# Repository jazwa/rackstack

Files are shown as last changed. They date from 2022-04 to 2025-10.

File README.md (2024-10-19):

# rackstack

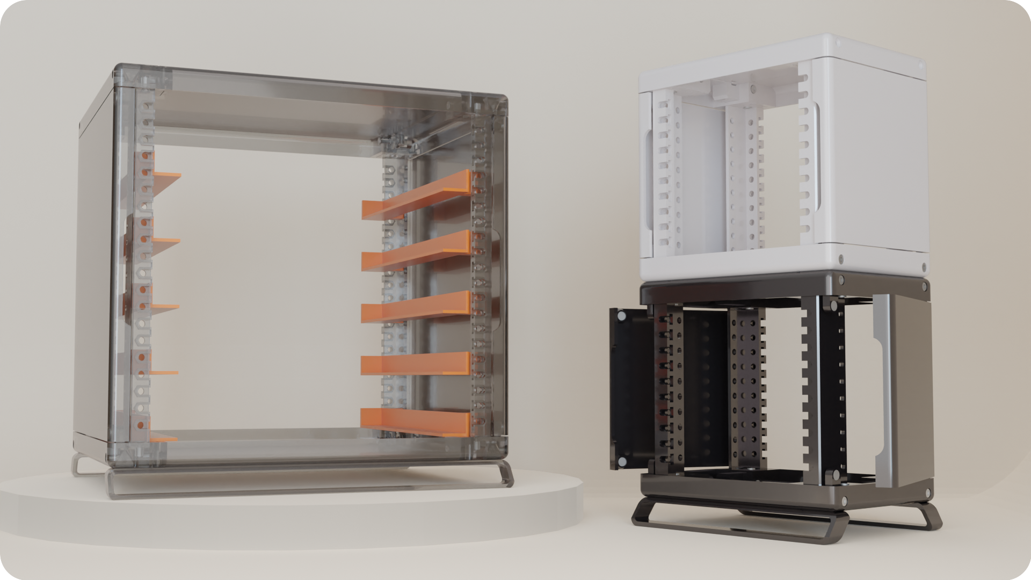
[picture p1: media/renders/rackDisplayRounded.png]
display


### A modular 3d-printable mini rack system
- ***Mount Anything:*** Perfect for organizing SBCs, mini PCs, small switches, power hubs, etc.
- ***Fully customizable:*** Fully written in OpenSCAD. Everything, from the dimensions of the rack, to the roundness of the corners, can be modified with a simple code change.
- ***Printable from home:*** Designed to be printed with conventional FDM printers. Requires minimal supports when printing, and final assembly needs only a few easy-to-source parts. 
- ***No cage nuts:*** Sliding hex nut design for the front rails allows one to easily mount items, without dealing with cage nuts.
- ***Stackable:*** Individual racks can be easily stacked and fastened together. Mix and match different color and design combinations!

## Assembly

Pre-generated STLs for roughly 200mm^3 (mini), 180mm^3 (micro), and 100mm^3 (nano) rack frames can be found in the [stl](stl) dir.
These STLs are generated from the files in [rack/print](rack/print) - further information about printing these parts 
(supports, orientation) can be found in these files.

### Assembly Instructions
Please see [the assembly guide](./assembly-guide).

### BOM - Required Tools:
- 3d FDM Printer - build size requirements depend on configured rack profile
- M3 Allen Key (for constructing the rack)
- M4 Allen Key (for mounting rack-mount items)

### BOM - Single Rack:

| Item | Name | Quantity | Comment |
|---|---|---|---|
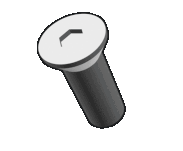
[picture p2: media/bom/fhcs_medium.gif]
|  | M3x12 FHCS | 12 | Extras are useful and inexpensive. If you plan on eventually stacking multiple racks together, don't hesitate to get a lot more. |
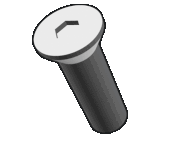
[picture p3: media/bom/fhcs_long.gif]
|  | M3x16 FHCS | 16 | ☝️ |
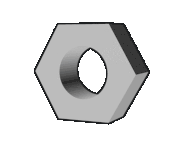
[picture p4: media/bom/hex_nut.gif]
|  | M3 hex nut | 28 | ☝️ |
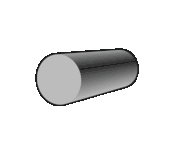
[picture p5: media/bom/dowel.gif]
|  | 3x10 steel dowel pin | 4 | 3mm diameter, 10mm height |
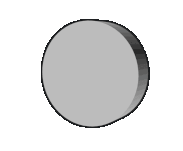
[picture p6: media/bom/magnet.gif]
|  | 6x2 neodymium disc magnet | 8 | 6mm diameter, 2mm height |
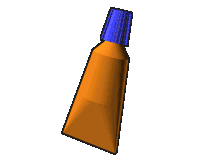
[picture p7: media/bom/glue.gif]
|  | super glue | \>= 2ml  | Used to glue magnets to plastic |

### Printing - Single Rack:
| Part | Quantity |
|---|---|
| [Left Y-Bar](./rack/print/yBarLeft_P.scad) | 2 |
| [Right Y-Bar](./rack/print/yBarRight_P.scad) | 2 |
| [X-Bar](./rack/print/xBar_P.scad) | 4 |
| [Main Rail](./rack/print/mainRail_P.scad) | 4 |
| [Left Side Wall](./rack/print/sideWallLeft_P.scad) | 1 |
| [Right Side Wall](./rack/print/sideWallRight_P.scad) | 1 |
| [XY-Plate](./rack/print/xyPlate_P.scad) | 2 |
| [Feet](./rack/print/rackFeet_P.scad) (optional) | 2 |

#### Notes: 
- ⚠️ Before printing the actual parts. It's recommended to print this evaluation part: [eval_P.scad](./rack/print/eval_P.scad) to test tolerances. 
  If you find the fits too tight/loose, you can adjust them [here](./config/print.scad). Please make sure also adjust the layer height in that file, too.
- Omitted actual plastic for printing. Any conventional 3d printing plastic should do (PLA, PETG, ABS),
but beware of PLA's thermal limits. Higher infill is recommended for all parts.
- For joining two racks, you will need to print 4 [rackJoiners](./rack/print/rackJoiner_P.scad), as well as 8 M3 hex nuts, and 8 M3x12 FHCS.
- Main front rails use M4 hex nuts and screws.
- Side rails are mounted using M3 hex nuts and screws.

## Configuring + Generating STLs
A python script:  [rbuild.py](./rbuild.py) is provided to generate different project stls. **Before running the script**, please 
configure the path to the OpenSCAD binary in [rbuild.py](./rbuild.py).

Requirements:
  - `openscad` CLI binary
  - `python3`

### Examples:
Generate all project files for the `micro` profile:

`python3 rbuild.py -b all -c micro`

This will build all the parts defined in [rack/print](./rack/print), and put the STLs in [stl/micro](./stl/micro). 
You can also provide a `-dz {n}` parameter to adjust the height of the generated rack. Configuring other rack
variables can be done in [config/rackframe.scad](./config/rackFrame.scad).

For generating a specific part, and putting it into a new `stl/custom` target directory: 

`python3 rbuild.py -b yBar -c micro -t custom`

`rbuild.py` also support an optional `--nightly` flag, which will run a nightly build of OpenSCAD. Please make sure the
path to the nightly build is also configured in [rbuild.py](./rbuild.py).

### ⚠️ Important:
Before committing to a full print, please try printing an evaluation print: [eval_P.scad](./rack/print/eval_P.scad) to test tolerances.
It is very likely you will need to edit the default tolerances in [print.scad](./config/print.scad) for a nice fit.

## Trays, Boxes, etc

Some parametric rack mount systems can be found in [rack-mount](./rack-mount). The following rack-mount systems 
are currently supported:
- [Enclosed Box](./rack-mount/enclosed-box): For mounting box-shaped objects, without the need for any mounting holes on the box.
- [Tray](./rack-mount/tray): Simple tray mounted using only the front rails. Can be configured to have screw mounts at the bottom of the tray.
- [Patch Panel](./rack-mount/patch-panel): Linear patch panel array. Number of keystone slots can be configured.
- [Angle Brackets](./rack-mount/angle-bracket): Simple Angle Bracket mounting system. Derived from the Enclosed Box system.

## Rack Mount Catalog

There is a small catalog of various pre-configured rack-mountable parts in the [catalog](./rack-mount/catalog) directory. Please feel free to add anything even remotely
useful!

## Designing rack-mount items

Some useful variables for designing your own rack-mount items can be found in [rack-mount/dimensionHelper.scad](./rack-mount/dimensionHelper.scad).

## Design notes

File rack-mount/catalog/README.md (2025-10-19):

# Rack Mount Catalog

A hodgepodge of various pre-configured rack mount parts. 

Please feel free to submit a pull request for any new parts you end up creating! Code quality is no object here.

Command to rebuild the preview images:
```
find . -name "*.scad" -exec ./build_catalog_preview.sh {} \;
```

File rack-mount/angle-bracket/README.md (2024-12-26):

# Angle Bracket System

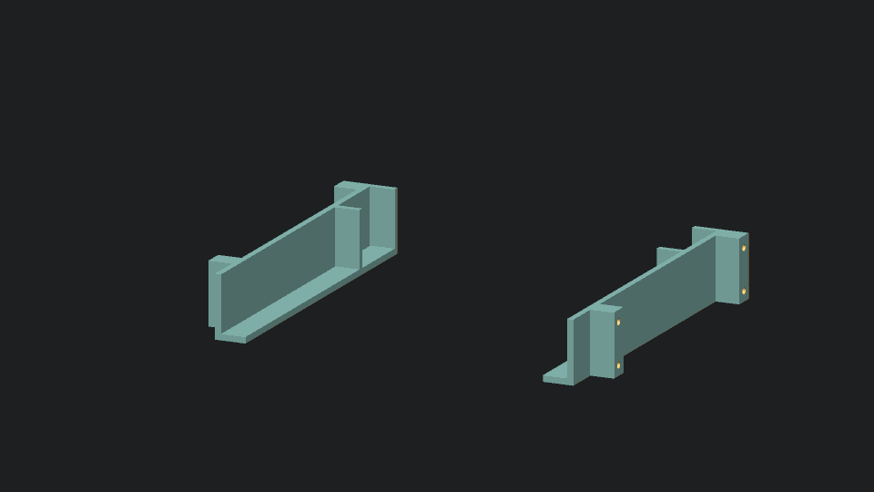
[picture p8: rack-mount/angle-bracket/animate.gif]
demo


Please see [entry.scad](./entry.scad) for config and building. Make sure the correct rack profile is configured in [rackFrame.scad](../../config/rackFrame.scad).

### BOM:

| Item | Name | Quantity | Comment |
|---|---|---|---|
|  | M3x12 FHCS | 8 | Extras are useful and inexpensive. If you plan on eventually stacking multiple racks together, don't hesitate to get a lot more. |
|  | M3 hex nut | 8 | ☝️ |

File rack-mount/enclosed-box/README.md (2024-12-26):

# Enclosed Box Mounting System

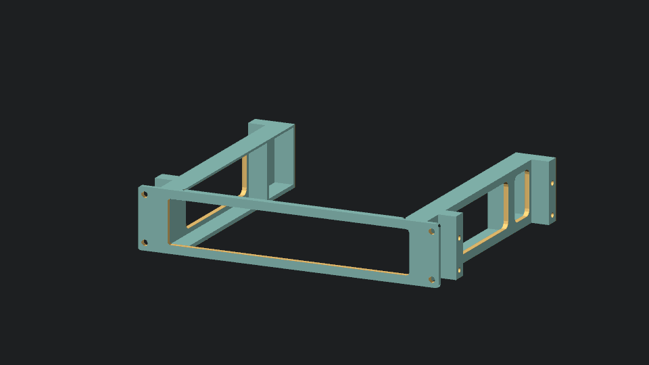
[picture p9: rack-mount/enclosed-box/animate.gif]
demo


Please see [entry.scad](./entry.scad) for config and building. Make sure the correct rack profile is configured in [rackFrame.scad](../../config/rackFrame.scad).

- This system comprises three parts: two side rails, and a front plate.
- This system is useful for mounting heavier box-shaped things. It works by first sliding in the box inside the side rails (which secures `x`, `z`, and one half of the `y` axis), and then mounting the front plate along the main rails (fully securing the `y` axis).
- Side rails will most likely require supports to print.
- For wider boxes (nearing the `maxUnitWidth` of the rack), you will have to set `recessSideRail` to true. This is so the side rails do not collide with the main rack rails. 

### BOM:

| Item | Name | Quantity | Comment |
|---|---|---|---|
|  | M3x12 FHCS | 8 | Extras are useful and inexpensive. If you plan on eventually stacking multiple racks together, don't hesitate to get a lot more. |
|  | M3 hex nut | 8 | ☝️ |
|  | M4x12 FHCS | 4 | ☝️ |
|  | M4 hex nut | 4 | ☝️ |

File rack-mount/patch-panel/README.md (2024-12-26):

# Patch Panel

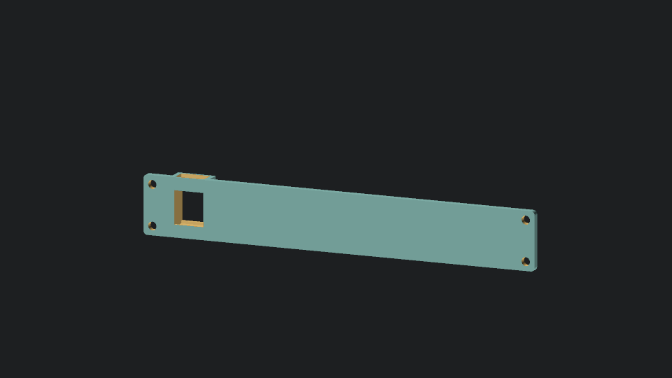
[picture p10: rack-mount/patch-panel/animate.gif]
demo


Please see [entry.scad](./entry.scad) for config and building. Make sure the correct rack profile is configured in [rackFrame.scad](../../config/rackFrame.scad).

- Mount RJ-45 keystone jacks with this part.
- Single part. Can be printed without supports.

### BOM:

| Item | Name | Quantity | Comment |
|---|---|---|---|
|  | M4x12 FHCS | 4 | Extras are useful and inexpensive. If you plan on eventually stacking multiple racks together, don't hesitate to get a lot more. |
|  | M4 hex nut | 4 | ☝️ |

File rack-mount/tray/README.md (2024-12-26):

# Tray Mounting System

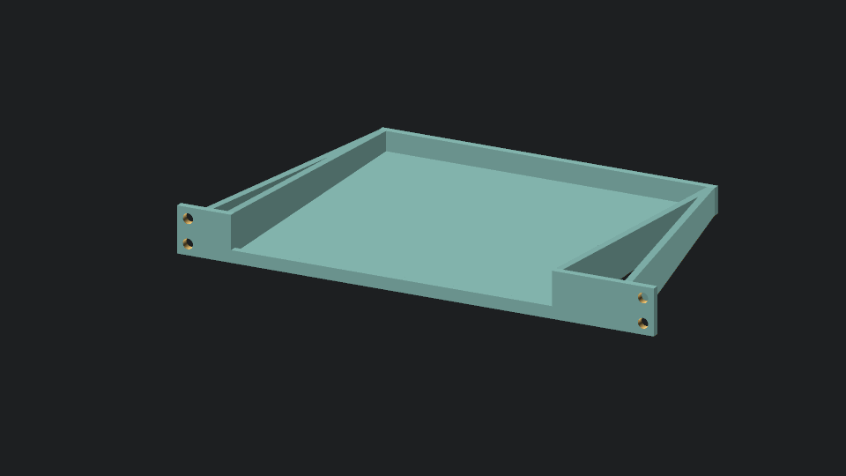
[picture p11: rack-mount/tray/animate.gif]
demo


Please see [entry.scad](./entry.scad) for config and building. Make sure the correct rack profile is configured in [rackFrame.scad](../../config/rackFrame.scad).

- Mount on front rails. 
- Single part. Can be printed without supports.
- Includes support for custom bottom screws (see `mountPoints` in config). This is useful for SBCs and mini PCs with bottom screws.

### BOM:

| Item | Name | Quantity | Comment |
|---|---|---|---|
|  | M4x12 FHCS | 4 | Extras are useful and inexpensive. If you plan on eventually stacking multiple racks together, don't hesitate to get a lot more. |
|  | M4 hex nut | 4 | ☝️ |

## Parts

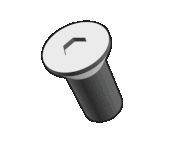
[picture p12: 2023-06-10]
media/bom/fhcs_short.gif

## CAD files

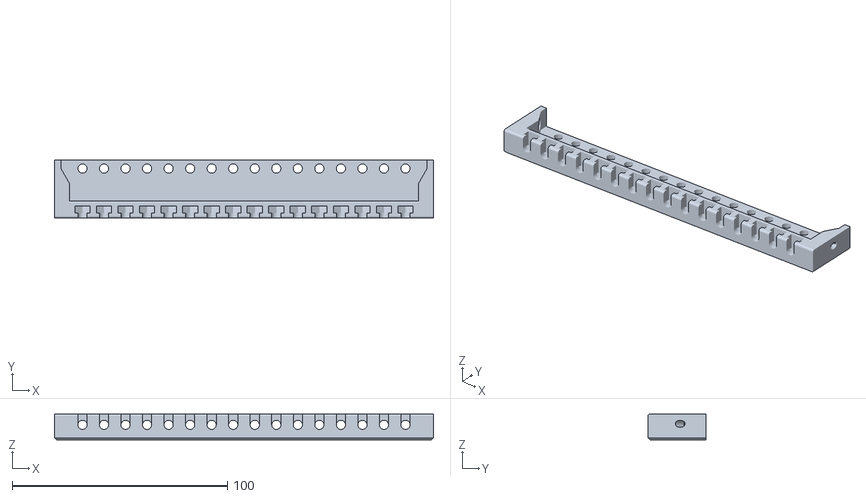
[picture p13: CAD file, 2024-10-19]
stl/mini/rack/mainRail_P.stl
176.0 x 27.0 x 12.0

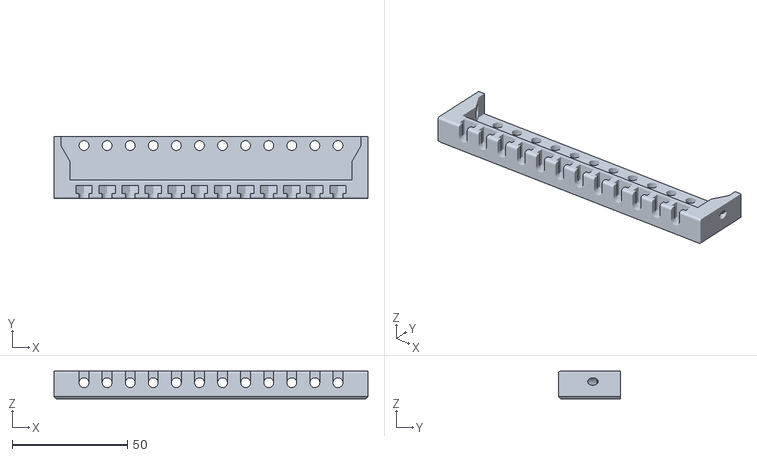
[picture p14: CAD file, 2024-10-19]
stl/micro/rack/mainRail_P.stl
136.0 x 27.0 x 12.0

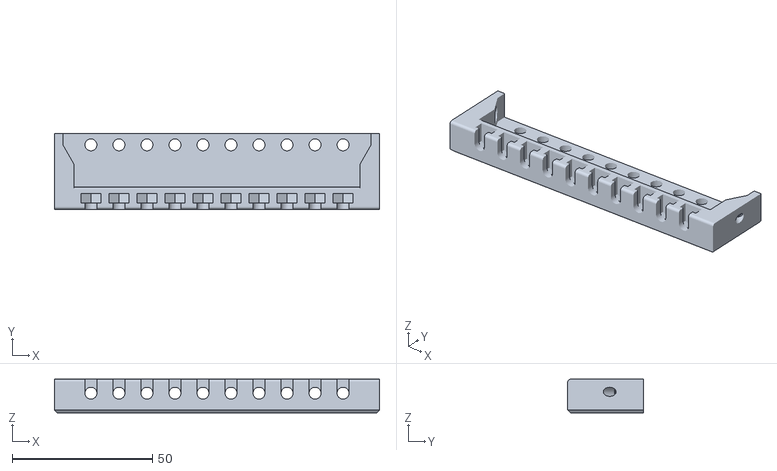
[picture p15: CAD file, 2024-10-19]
stl/nano/rack/mainRail_P.stl
116.0 x 27.0 x 12.0

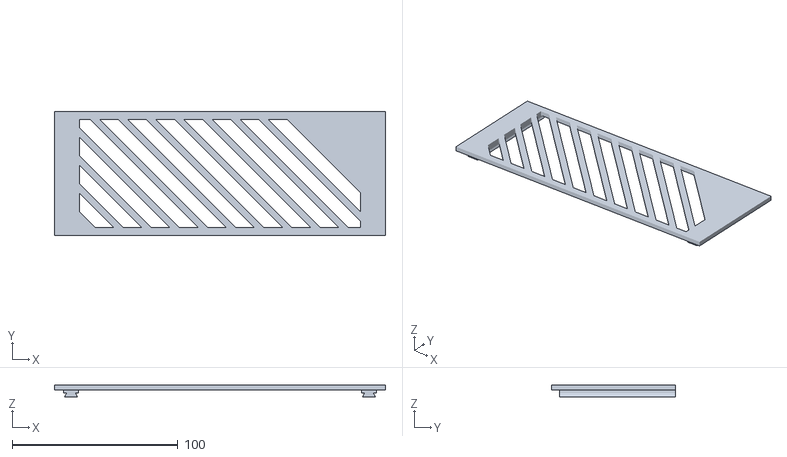
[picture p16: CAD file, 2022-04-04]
power/src/plate.stl
200.0 x 75.0 x 7.33

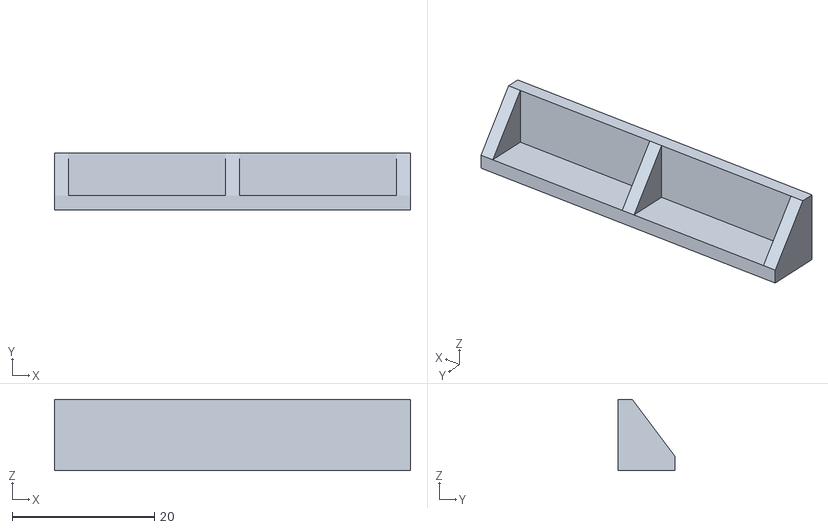
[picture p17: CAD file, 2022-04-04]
power/stl/support1.stl
50.0 x 8.00 x 10.0

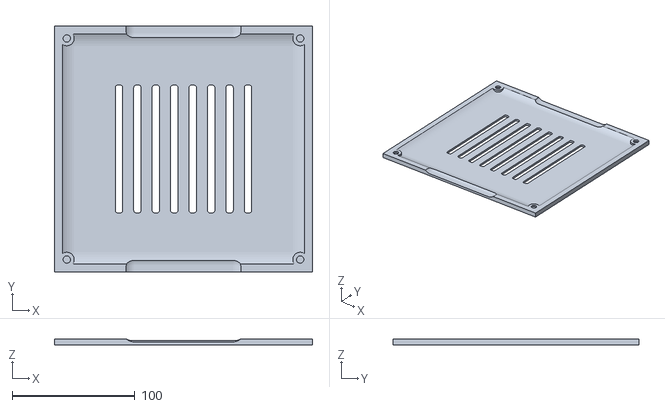
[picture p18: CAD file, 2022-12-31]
rack/body/side/side.stl
210.0 x 200.0 x 5.00

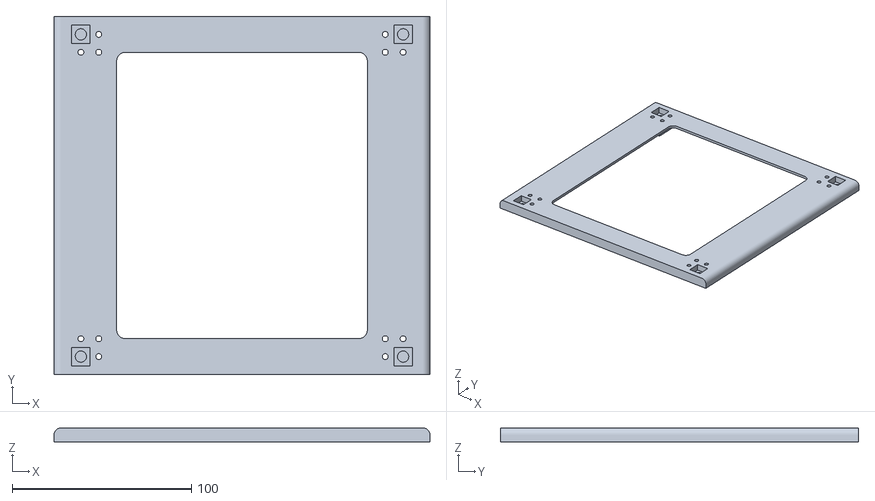
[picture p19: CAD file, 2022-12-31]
rack/body/top1.stl
210.0 x 200.0 x 8.01

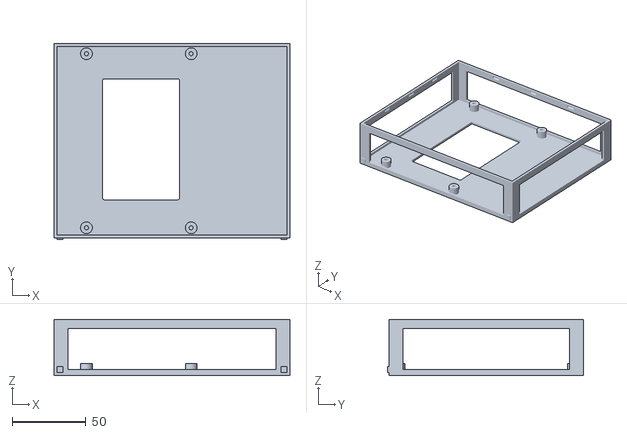
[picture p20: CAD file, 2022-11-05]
rack/rackCase.stl
160.0 x 133.0 x 38.0

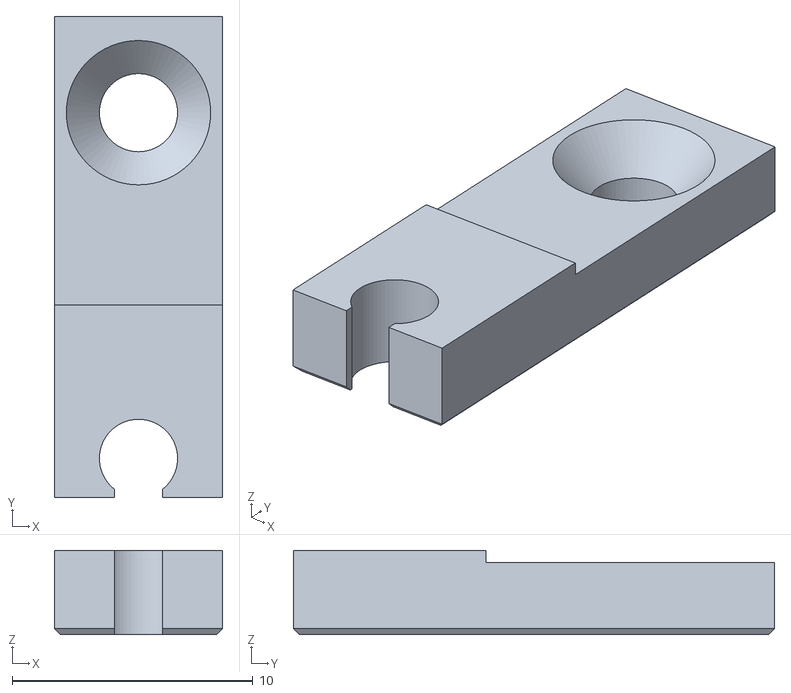
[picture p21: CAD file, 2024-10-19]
stl/micro/rack/hingeModule.stl
7.00 x 20.0 x 3.50

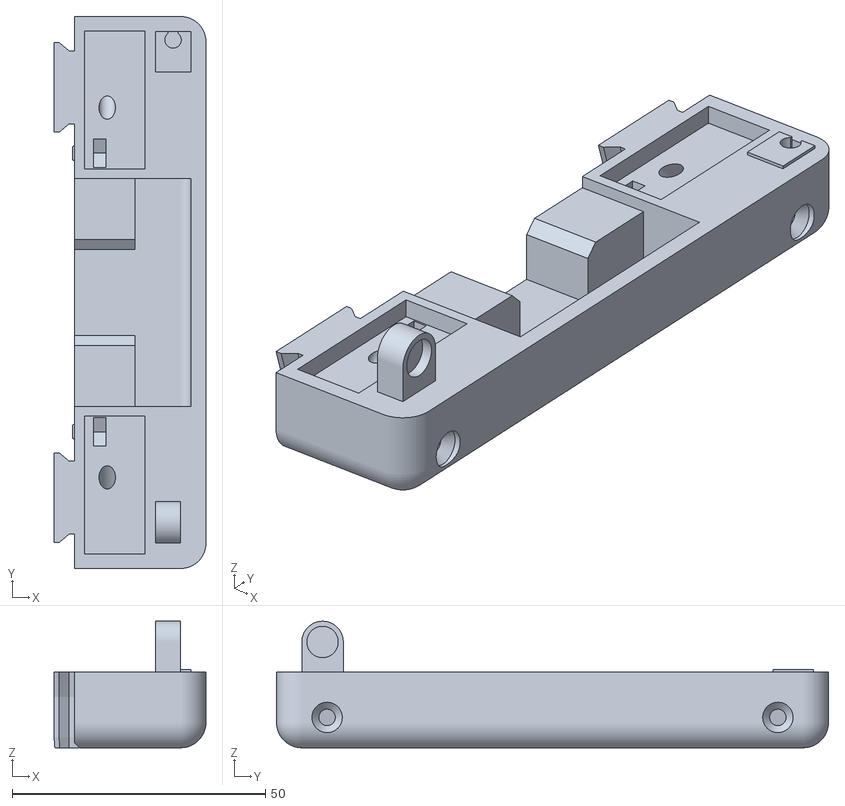
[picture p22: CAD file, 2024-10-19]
stl/nano/rack/yBarRight_P.stl
30.0 x 109.0 x 25.0

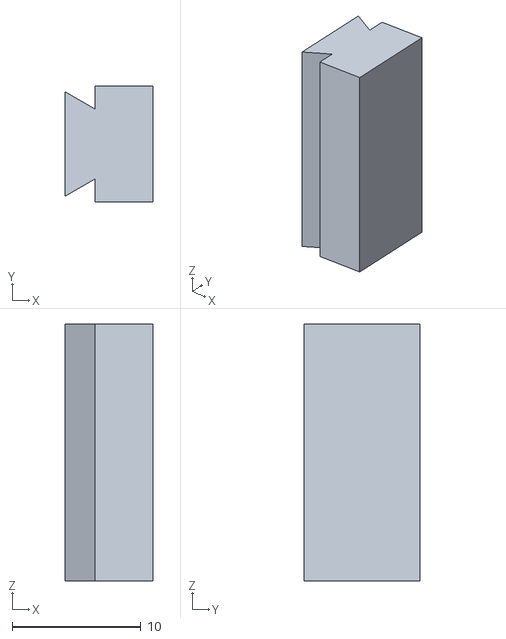
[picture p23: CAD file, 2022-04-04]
power/stl/railInsert.stl
6.85 x 9.00 x 20.0

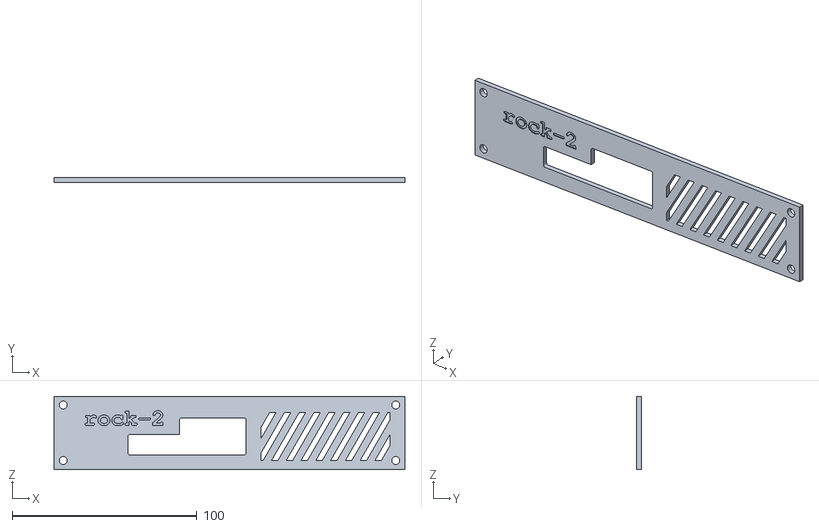
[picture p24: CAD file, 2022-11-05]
rack/rackCaseFrontPlate.stl
190.0 x 2.50 x 39.8

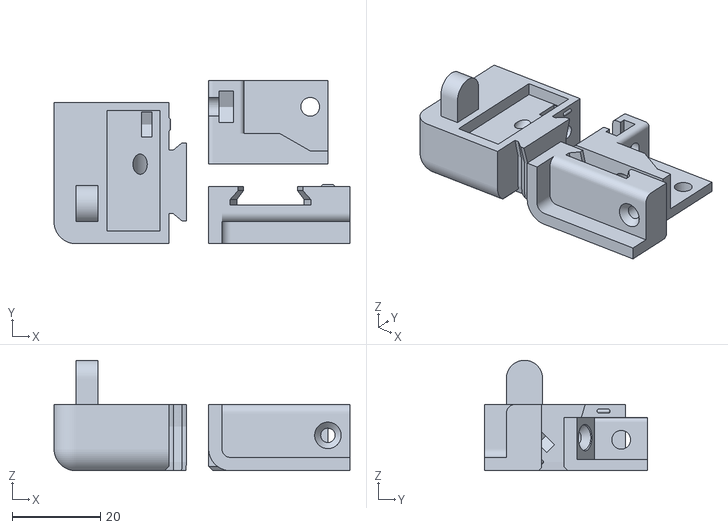
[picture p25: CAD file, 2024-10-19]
stl/micro/rack/eval_P.stl
67.0 x 37.0 x 25.0

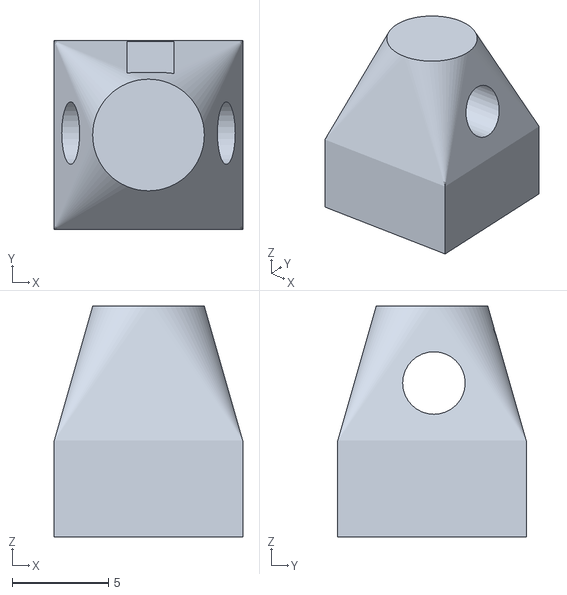
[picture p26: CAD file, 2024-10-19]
stl/mini/rack/stackConnectorBottom_P.stl
9.80 x 9.80 x 12.0

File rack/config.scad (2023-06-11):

/*
   case-files v2
   This file contains parameters used for declaring/generating a customized rack frame.

   - All dimensions are in millimetres (mm) unless stated otherwise.
   - "_N" appended to a module is meant to denote that this module is a negative volume, and should only be used to
     substract from other volumes. "_P" is meant to denote a positive value. Modules are positive by default.
*/
include <./profiles.scad>

// Manually set this variable to toggle profiles
profileName = "micro";

profile = getProfile(profileName);

defaultLayerHeight = 0.3;

function getConfig(name) = getConfigValue(profile, name);

// Maximum width for rack-mount units. Change this according your max expected enclosure width.
// Changing this will directly affect the required build volume.
maxUnitWidth = getConfig("maxUnitWidth");

// Maximum (recommended) unit depth. There technically isn't a max unit depth because there's no physical bound on
// how far a rack unit can extrude back. This parameter basically controls the distance between the front of the front
// rails and the back of the back rails. Changing this will directly affect the required build volume.
maxUnitDepth = getConfig("maxUnitDepth");

// Vertical distance between the midpoint of adjacent screws mounts. Affects build volume.
screwDiff = getConfig("screwDiff");

// Number screw slots on the main rail. Affects build volume.
numRailScrews = getConfig("numRailScrews");

// Screw type used for rackmount units. See screws.scad.
mainRailScrewType = getConfig("mainRailScrewType");

// Screw type used to affix side rails.
mainRailSideMountScrewType = getConfig("mainRailSideMountScrewType");

// Screw type used for constructing the actual rack frame.
rackFrameScrewType = getConfig("rackFrameScrewType");
// Currently, only m3 screws are supported here (tolerance issues)
assert(rackFrameScrewType == "m3");

// Fillet radius for main rack profile
baseRoundness = getConfig("baseRoundness");

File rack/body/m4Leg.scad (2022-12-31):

include <../../common.scad>
include <../screws.scad>


//slack = 0.5;
//m3Diameter = 3.0;
//m3Radius = m3Diameter/2.0;
//m3ptr = m3Radius + slack;

legWidth = 16;
legLength = 16;
legHeight = 60;

legFrontThickness = 6;
legSupportThickness = 4;

legWingThickness = 4;
legWingLength = 9;

// 9.5 to account for space for inserting hex nuts at the top
legWingWidth = 9.5+legSupportThickness;


module legWing() {
  difference() {
    cube(size=[legWingLength, legWingThickness, legWingWidth]);

    union() {
      translate(v=[4,0,10])
        rotate(a=[90,0,0])
        cylinder(r=m3RadiusSlacked, h=20, center=true);

      translate(v=[14,0,10])
        rotate(a=[90,0,0])
        cylinder(r=m3RadiusSlacked, h=20, center=true);
    }
  }
}

module base() {
    difference() {
      cube(size=[25,25,legWingThickness]);

      union() {
      translate(v=[20,20,0])
        cylinder(r=m3RadiusSlacked, h=100, center=true);

      translate(v=[10,10,0])
        cylinder(r=m3RadiusSlacked, h=100, center=true);

      translate(v=[20,10,0])
        cylinder(r=m3RadiusSlacked, h=100, center=true);

      translate(v=[10,20,0])
        cylinder(r=m3RadiusSlacked, h=100, center=true);
      }
      
    }
}

module baseLeg(legHeight) {
  union() {
    difference() {
      cube(size=[16,16, legHeight]);

      union() {
        translate(v=[4,6,0])
          cube(size=[16, 16, legHeight]);

        // compensate for differences between leg/wing thickness
        translate(v=[legSupportThickness,legSupportThickness,0])
          cube(size=[legWidth,legWidth,legSupportThickness+10]);

        translate(v=[legSupportThickness,legSupportThickness,legHeight-legWingWidth])
          cube(size=[legWidth,legWidth,legSupportThickness+10]);

      }
    }

    translate(v=[16,0,0])
      legWing();


    translate(v=[16,0,legHeight])
      mirror(v=[0,0,1]) {
      legWing();
    }

    mirror(v=[1,-1,0]) {
      translate(v=[16,0,0])
        legWing();


      translate(v=[16,0,legHeight])
        mirror(v=[0,0,1]) {
        legWing();
      }
    }

  }

  base();

  translate(v=[0,0,legHeight-legWingThickness])
    base();
}

*baseLeg(180);

module leg(ui) {
  assert(ui > 0);

  legLength = 20 + (ui-1)*10;
  
  difference() {
    baseLeg(legLength);

    union() {
        
      intersection() {
        union() {
          for (i = [1:ui-2]) {
            translate(v=[0,10,(i+1)*10])
              rotate(a=[0,90,0])
              *cylinder(h = 100, r = m3ptr, $fn=32, center=true);

            translate(v=[10,3,(i+1)*10])
              rotate(a=[90,-10,0])
              m4HexNutPocketNegative();
          }
        }      
        translate(v=[-1,-1,legWingWidth])
          cube(size=[1000,1000,legLength-2*legWingWidth]);
      }

      translate(v=[0,10,10])
        rotate(a=[0,90,0])
        cylinder(h = 100, r = m3ptr, $fn=32, center=true);

      translate(v=[0,10,ui*10])
        rotate(a=[0,90,0])
        cylinder(h = 100, r = m3ptr, $fn=32, center=true);


      translate(v=[10,0,10])
        rotate(a=[90,0,0])
        cylinder(h = 100, r = m3ptr, $fn=32, center=true);

      translate(v=[10,0,ui*10])
        rotate(a=[90,0,0])
        cylinder(h = 100, r = m3ptr, $fn=32, center=true);
    }
  }
}


//mirror(v=[1,0,0])
leg(20);

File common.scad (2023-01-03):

/* Some initial configurations and commonly used variables
   plus functions
*/

$fn=64;

eps=0.0001;

inf10 = 10;
inf50 = 50;
inf1000 = 1000;
inf = inf1000;

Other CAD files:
stl/nano/rack/hingeModule.stl
power/stl/topBarInsert.stl
rack/rackCaselid.stl
stl/micro/rack/rackFeet_P.stl
sinusoid.scad
cases/rack-tray/rack-tray.scad
cases/rack/base1.scad
cases/rpi/frontPlate.scad
cases/rpi/rpi2b.scad
cases/rpi/top.scad
config/common.scad
config/dowel.scad
config/magnet.scad
config/print.scad
config/rackFrame.scad
config/slack.scad
helper/apply.scad
helper/common.scad
helper/dovetail.scad
helper/filet.scad
helper/keystone.scad
helper/keystone1.scad
helper/keystone2.scad
helper/math.scad
helper/matrix.scad
helper/screws.scad
helper/sine.scad
helper/sinusoid.scad
helper/slack.scad
misc/bomAnimations.scad
power/src/Untitled.scad
power/src/base.scad
power/src/join.scad
power/stl/backPlate.stl
power/stl/feet.stl
power/stl/joinTest.stl
power/stl/joinTest\.stl
power/stl/legTest.stl
power/stl/plate.stl
power/stl/screwtest.stl
power/stl/support2.stl
power/stl/top.stl
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

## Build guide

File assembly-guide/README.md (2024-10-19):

# Rack Assembly Instructions

**Note**: Please see
- [BOM](../README.md#bom---single-rack) for required materials, beyond the actual 3D printed parts.
- [Print BOM](../README.md#printing---single-rack) for all the required 3D printed parts for a single rack.

## Instructions:
Slide in M3 hex nuts into the Y-bars - 4 times. Each corner should have 3 hex nuts:
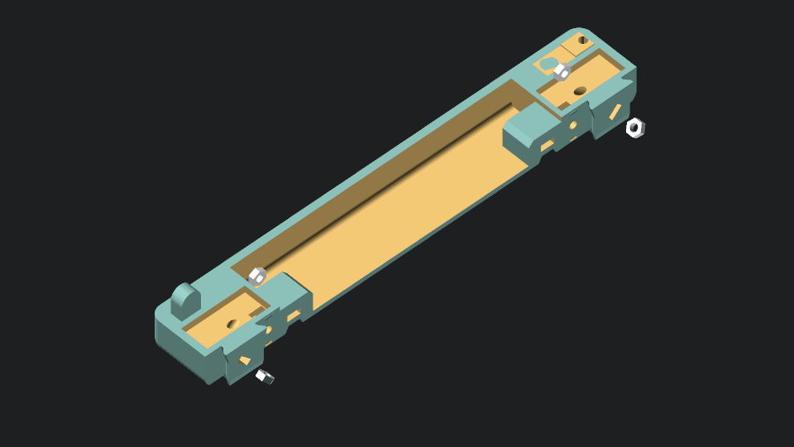
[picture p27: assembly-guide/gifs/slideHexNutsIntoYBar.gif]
slideHexNutsIntoYBar


Glue magnets into magnet side-modules on the Y-bars - 4 times:
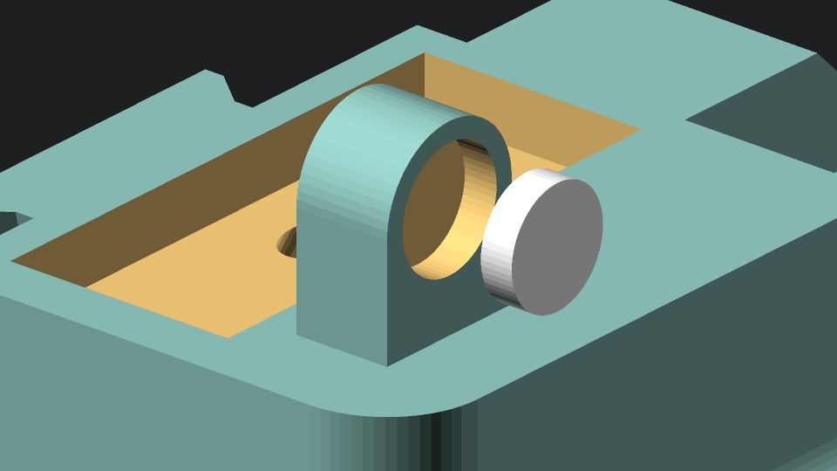
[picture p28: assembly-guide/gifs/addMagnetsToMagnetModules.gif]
addMagnetsToMagnetModules


Glue top and bottom magnets into side walls - 2 times:
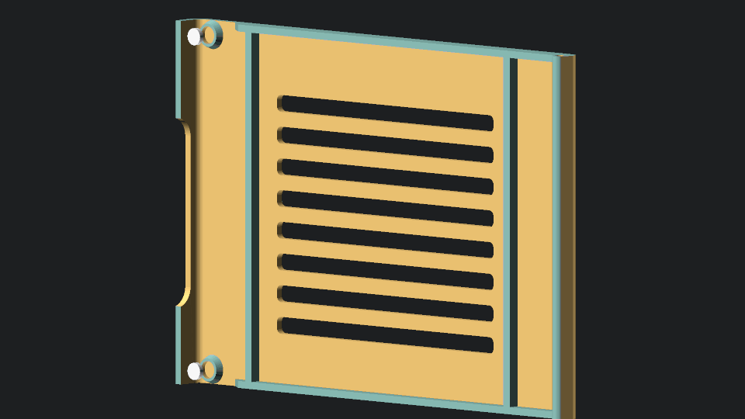
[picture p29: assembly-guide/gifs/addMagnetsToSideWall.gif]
addMagnetsToSideWall


Insert top and bottom dowel rods into side walls - 2 times:
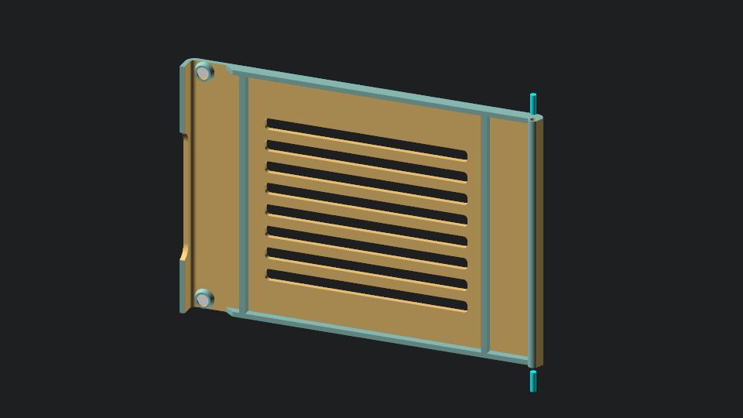
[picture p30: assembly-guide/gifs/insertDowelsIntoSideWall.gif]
insertDowelsIntoSideWall


Slide Y-bars into X-bars. Do this 2 times. You should end up with 2 trays. Orientation on the Y-bars matters here; make sure that the magnets are on the same side:
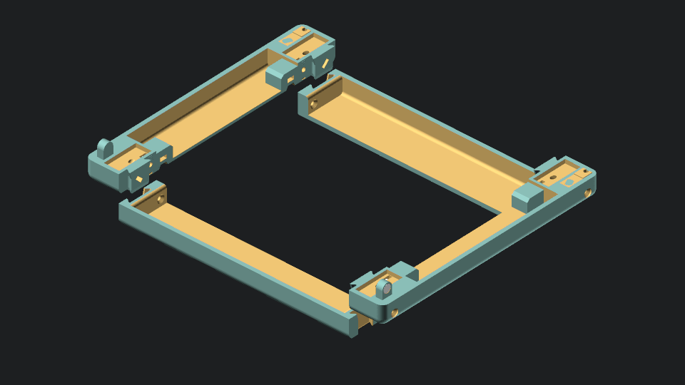
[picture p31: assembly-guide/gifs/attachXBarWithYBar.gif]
attachXBarWithYBar


Screw together Y-bars and X-bars using 4 M3x16 FHCS screws (one screw per corner) - 2 times: 
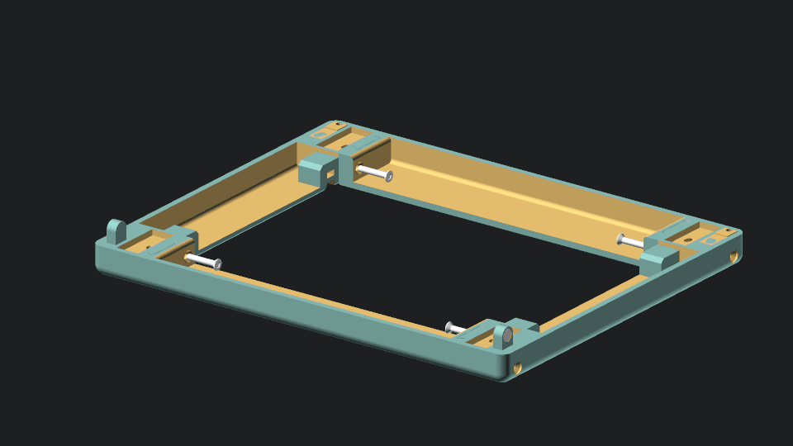
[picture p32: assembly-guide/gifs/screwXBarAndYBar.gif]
screwXBarAndYBar


<!-- This step is only needed if the fixedSideModules is set to false. -->
<!-- Screw in the side-modules with M3x8 FHCS screws. Orientation matters here. The magnets modules should be on the eventual front side, facing outwards, and the two hinge modules should be in the back. Do this 2 times (for both trays): -->
<!-- ![attachSideConnectorModulesToYBars](./gifs/attachSideConnectorModulesToYBars.gif) -->

Screw in the main rails with M3x16 FHCS screws.
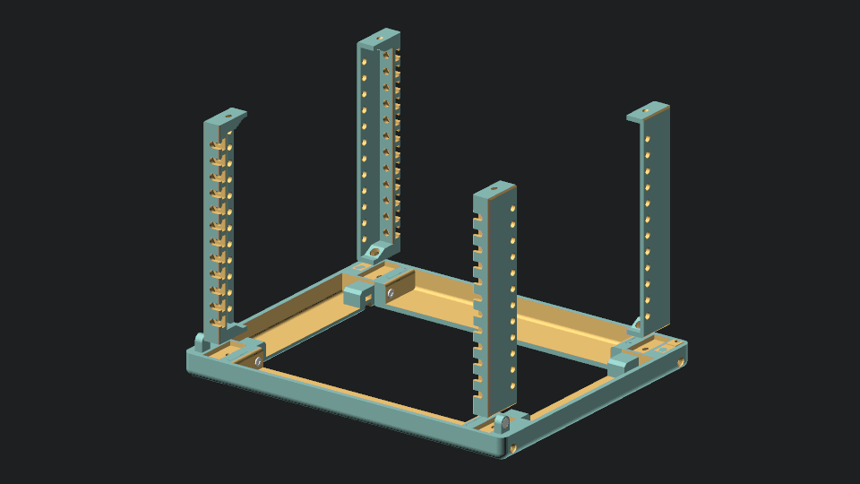
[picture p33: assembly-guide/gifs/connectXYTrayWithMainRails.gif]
connectXYTrayWithMainRails


Prop us the side wall using the side modules. Make sure the dowels are inserted properly, and the magnets align:
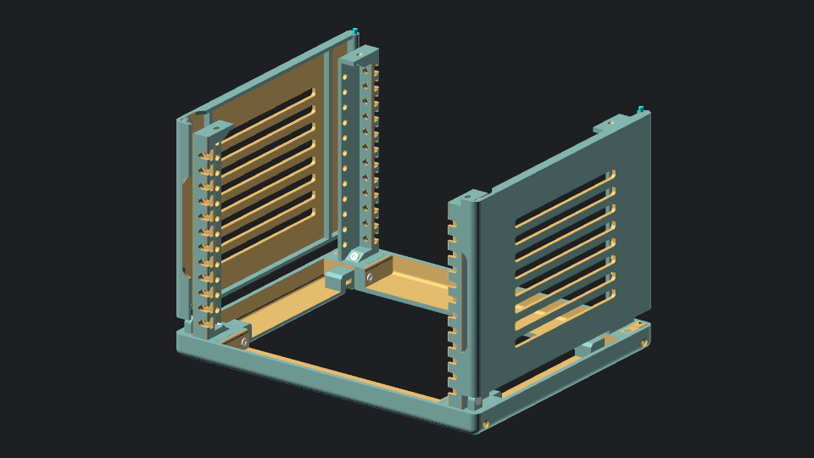
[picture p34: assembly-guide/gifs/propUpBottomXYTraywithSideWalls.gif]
propUpBottomXYTraywithSideWalls


Slide in the other (top) tray. Make sure the magnets and dowels align. Screw in the main rails with M3x16 FHCS screws:
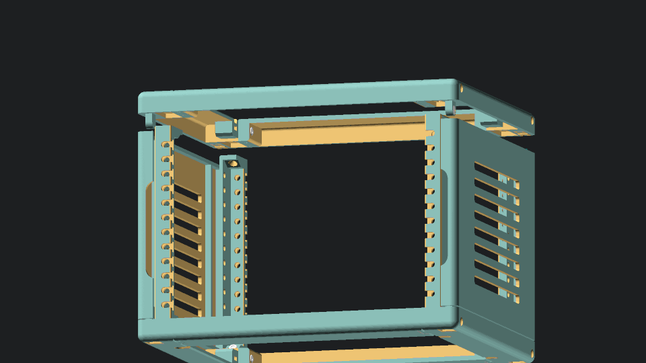
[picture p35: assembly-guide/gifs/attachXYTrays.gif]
attachXYTrays


Attach the top and bottom plates with 4 M3x12 screws each:
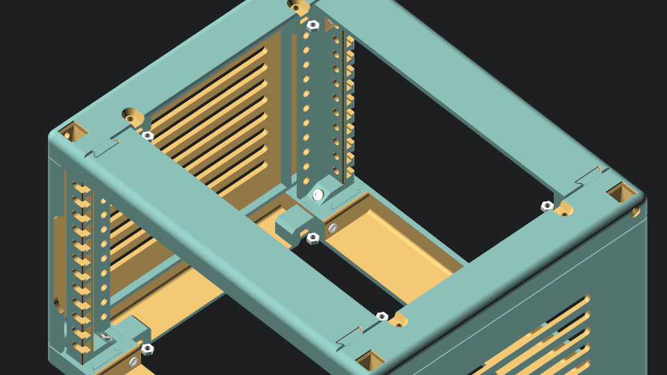
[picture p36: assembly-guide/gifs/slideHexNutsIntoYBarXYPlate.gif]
slideHexNutsIntoYBarXYPlate

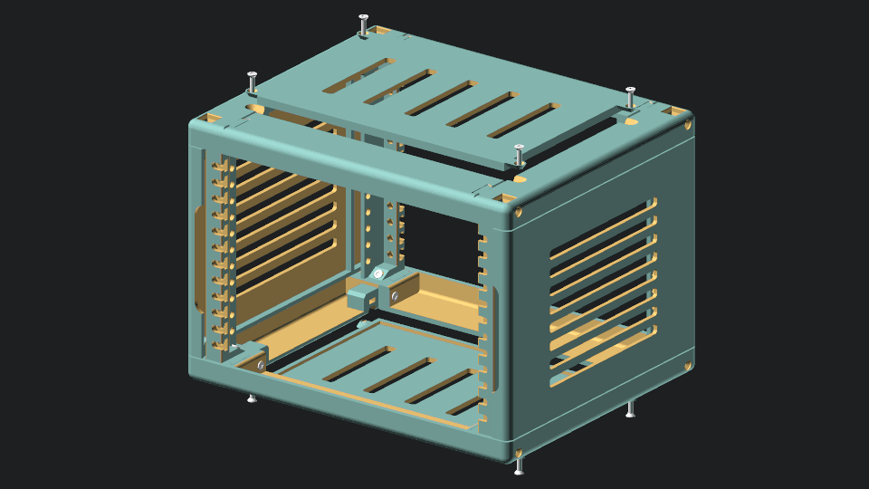
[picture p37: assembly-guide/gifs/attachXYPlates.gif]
attachXYPlates


Slide in hex nuts into feet - 2 times:
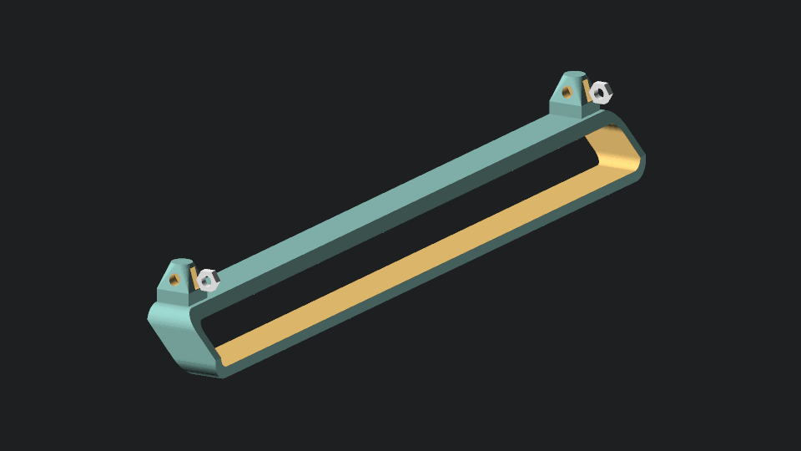
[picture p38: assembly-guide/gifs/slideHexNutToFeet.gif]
slideHexNutToFeet


Insert feet into the bottom of the rack: 
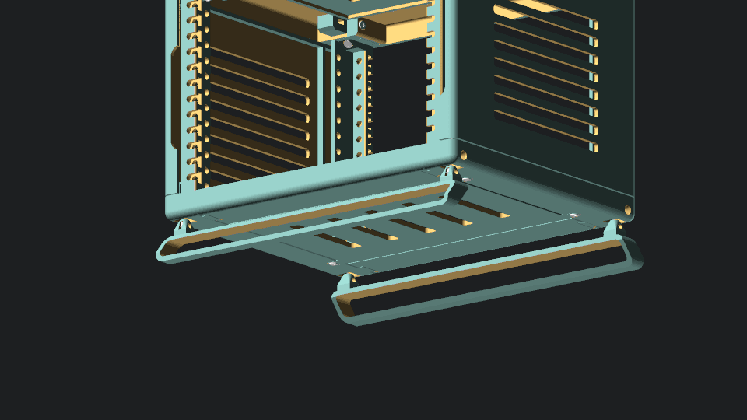
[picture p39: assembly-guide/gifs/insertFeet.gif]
insertFeet


Screw in feet using 4 M3x12 FHCS screws:
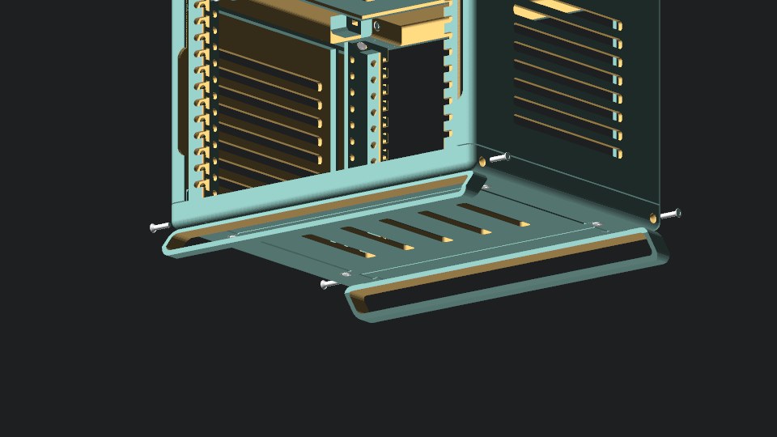
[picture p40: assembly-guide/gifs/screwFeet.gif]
screwFeet


**FIN**

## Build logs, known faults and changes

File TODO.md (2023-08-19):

# case-project TODO list

### Actual TODO

- Finish refactoring files to use the application style, like in `yBar.scad`.
- Figure out why sidewall build is so slow.
- Clean up `sharedVariables.scad`.
- Parallel builds with cli tool. 
- Beef up rack-mount designs.
- Make handles.

### Ideas
- Start using matrices for transformations. Enforce strict local/global hierarchy of matrix transformations. (Kinda done)
- GitHub CI for OpenSCAD stl building
- Instead of using names like 'mainRailSlotToInnerYZFace', experiment with a central distance/dimension directory. Like:
```openscad
// Define identifiers:
mainRailSlot = "mainRailSlotIdentifier";
yBarInnerYZ = "yBarInnerYZFaceIdentifier";

// Define distance
setDx(mainRailSlot, yBarInnerYZ, 3);

// Define dimensions
setX(mainRailSlot, 10);
setX(yBarInnerYZ, 0);

// Then, you can get distances like:
dx(mainRailSlot, yBarInnerYZ); // == 3
dx(yBarInnerYZ, mainRailSlot); // == 3

dx(mainRailSlot, blah); //throw error

// And you could possible chain distances like:

dx(yBarInnerYZ, mainRailSlot, sideConnectorSlot); 
// which would eval to:
// dx(yBarInnerYZ, mainRailSlot) + x(mainRailSlot) + dx(mainRailSlot, sideConnectorSlot); 
// OR 
dx(yBarInnerYZ, mainRailSlot, sideConnectorSlot, includeFirst=true, includeLast=true);
// which would eval to:
// x(yBarInnerYZ) + dx(yBarInnerYZ, mainRailSlot, sideConnectorSlot) + x(sideConnectorSlot);
```
Hmm after looking into it a bit it seems that OpenScad's non-reassign rule is going to get in the way. Might still be
worthwhile implement variable subsystem?

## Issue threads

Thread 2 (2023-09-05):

How can I generate rack-mount items?

marcelbaarsch, 2023-09-05:
Can I use rbuild.py to generate an stl of rack-mount items such as patchPanel?

jazwa, 2023-09-05:
Not currently. For rack-mount items, I just suggest firing up Openscad (the program) and building the `entry.scad` file manually.
For patch panels it would be https://github.com/jazwa/rackstack/blob/main/rack-mount/patch-panel/entry.scad

Closed 2024-08-26.

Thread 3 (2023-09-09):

[Feature Request] Windows rbuild.py

miketweaver, 2023-09-09:
I'm not sure why the instructions don't have windows support.

I was able to build just fine on windows:

```
PS C:\Users\User\Downloads\rackstack-1.1.1> python3.exe '.\rbuild.py' -b all -c micro
Building: eval_P.scad from C:\Users\User\Downloads\rackstack-1.1.1\rack/print to C:\Users\User\Downloads\rackstack-1.1.1\stl\micro\rack
C:\Users\User\Downloads\rackstack-1.1.1\rack/print C:\Users\User\Downloads\rackstack-1.1.1\stl\micro\rack eval_P.scad
Building: hingeModule.scad from C:\Users\User\Downloads\rackstack-1.1.1\rack/print to C:\Users\User\Downloads\rackstack-1.1.1\stl\micro\rack
C:\Users\User\Downloads\rackstack-1.1.1\rack/print C:\Users\User\Downloads\rackstack-1.1.1\stl\micro\rack hingeModule.scad
Building: magnetModuleLeft_P.scad from C:\Users\User\Downloads\rackstack-1.1.1\rack/print to C:\Users\User\Downloads\rackstack-1.1.1\stl\micro\rack
C:\Users\User\Downloads\rackstack-1.1.1\rack/print C:\Users\User\Downloads\rackstack-1.1.1\stl\micro\rack magnetModuleLeft_P.scad
Building: magnetModuleRight_P.scad from C:\Users\User\Downloads\rackstack-1.1.1\rack/print to C:\Users\User\Downloads\rackstack-1.1.1\stl\micro\rack
C:\Users\User\Downloads\rackstack-1.1.1\rack/print C:\Users\User\Downloads\rackstack-1.1.1\stl\micro\rack magnetModuleRight_P.scad
Building: mainRail_P.scad from C:\Users\User\Downloads\rackstack-1.1.1\rack/print to C:\Users\User\Downloads\rackstack-1.1.1\stl\micro\rack
C:\Users\User\Downloads\rackstack-1.1.1\rack/print C:\Users\User\Downloads\rackstack-1.1.1\stl\micro\rack mainRail_P.scad
Building: rackFeet_P.scad from C:\Users\User\Downloads\rackstack-1.1.1\rack/print to C:\Users\User\Downloads\rackstack-1.1.1\stl\micro\rack
C:\Users\User\Downloads\rackstack-1.1.1\rack/print C:\Users\User\Downloads\rackstack-1.1.1\stl\micro\rack rackFeet_P.scad
Building: rackJoiner_P.scad from C:\Users\User\Downloads\rackstack-1.1.1\rack/print to C:\Users\User\Downloads\rackstack-1.1.1\stl\micro\rack
C:\Users\User\Downloads\rackstack-1.1.1\rack/print C:\Users\User\Downloads\rackstack-1.1.1\stl\micro\rack rackJoiner_P.scad
Building: sideWallLeft_P.scad from C:\Users\User\Downloads\rackstack-1.1.1\rack/print to C:\Users\User\Downloads\rackstack-1.1.1\stl\micro\rack
C:\Users\User\Downloads\rackstack-1.1.1\rack/print C:\Users\User\Downloads\rackstack-1.1.1\stl\micro\rack sideWallLeft_P.scad
Building: sideWallRight_P.scad from C:\Users\User\Downloads\rackstack-1.1.1\rack/print to C:\Users\User\Downloads\rackstack-1.1.1\stl\micro\rack
C:\Users\User\Downloads\rackstack-1.1.1\rack/print C:\Users\User\Downloads\rackstack-1.1.1\stl\micro\rack sideWallRight_P.scad
Building: stackConnectorBottom_P.scad from C:\Users\User\Downloads\rackstack-1.1.1\rack/print to C:\Users\User\Downloads\rackstack-1.1.1\stl\micro\rack
C:\Users\User\Downloads\rackstack-1.1.1\rack/print C:\Users\User\Downloads\rackstack-1.1.1\stl\micro\rack stackConnectorBottom_P.scad
Building: xBar_P.scad from C:\Users\User\Downloads\rackstack-1.1.1\rack/print to C:\Users\User\Downloads\rackstack-1.1.1\stl\micro\rack
C:\Users\User\Downloads\rackstack-1.1.1\rack/print C:\Users\User\Downloads\rackstack-1.1.1\stl\micro\rack xBar_P.scad
Building: xyPlate_P.scad from C:\Users\User\Downloads\rackstack-1.1.1\rack/print to C:\Users\User\Downloads\rackstack-1.1.1\stl\micro\rack
C:\Users\User\Downloads\rackstack-1.1.1\rack/print C:\Users\User\Downloads\rackstack-1.1.1\stl\micro\rack xyPlate_P.scad
Building: yBar_P.scad from C:\Users\User\Downloads\rackstack-1.1.1\rack/print to C:\Users\User\Downloads\rackstack-1.1.1\stl\micro\rack
C:\Users\User\Downloads\rackstack-1.1.1\rack/print C:\Users\User\Downloads\rackstack-1.1.1\stl\micro\rack yBar_P.scad
```

I had to add `r` to the beginning of the strings, but after that, it worked great.

```
# ------------- EDIT THESE VARIABLES WITH THE LOCATION OF YOUR OPENSCAD BINARIES
PATH_TO_OPENSCAD = r'C:\Users\User\scoop\apps\openscad\2021.01\openscad.exe'
PATH_TO_OPENSCAD_NIGHTLY = r'C:\Users\User\scoop\apps\openscad-dev\2023.09\openscad.exe'
```

jazwa, 2023-09-10:
That's actually really good to know. I have no experience with windows development so I just called it unsupported. Let me just confirm this works on a windows box...

jazwa, 2023-09-14:
Confirmed locally. I've changed the READMEs and added some extra comments in `rbuild.py`. Thank you for the suggestion!

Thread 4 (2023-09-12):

[Feature Request] 10-Inch Mini Rack

TeaRex-coder, 2023-09-12:
Hey Jazwa!

I saw your post on [r/homelab](https://www.reddit.com/r/homelab/comments/15wfot0/rackstack_an_opensource_3d_printable_mini_rack) and this seems like a super cool project!

I'd be down to print rackstack in a 10-inch mini rack form factor. I tried to do this myself but couldn't figure out how to do so in OpenSCAD :(

The changes that would have to be made are:
- Increase width to 10 inches (currently possible by adding a custom profile in `rackFrame.scad`)
- Use the EIA-310 rack unit spacing
- Accommodate M6 hardware for rack mount-items
- Increase `mainRail.scad` width and depth to accommodate larger M6 hardware

Thanks for your project, and if you're able to do this I'd 100% be down to test a prototype!

jazwa, 2023-09-14:
This has been requested by a couple of people already. I'll look into when I get the time. (I don't think it would be a lot of work, but I'm probably going to eat those words later.) Thank you for your interest!

lloydw, 2024-07-20:
Hi there, I just found your project and it looks amazing! I’m interested in printing a 10” version of this too and was wondering if either of you had got any further with the required changes? Thanks!

seantbaker, 2024-08-19:
I'm new to networking racks and openSCAD, but am I correct that items 2-4 in the OP are only needed if you're trying to make the printed rack compatible with standard 10" mini racks?

In other words, if I was going to stick to the rackstack ecosystem and print my own mounts for switches, routers, etc., would I only need the first item?

> Increase width to 10 inches (~255mm)  (currently possible by adding a custom profile in rackFrame.scad)

Thanks!

TeaRex-coder, 2024-08-21:
That's right, you would only need to increase the width to 10" from the outing of each rail or ~9.312" from the inside. Then you could use Rackstack's uniform hole spacing and M3 hardware.

TomacGG, 2024-09-30:
That's the only thing that i have to do, how to get the 10 inch mounting in the front, the squares?

cvrt-jh, 2025-01-30:
any progress on this?  printed out the whole thing and figured out later it is not really 10' :D

lipusal, 2025-03-03:
Hello! Adding my +1 to this feature request. I've spent the last several days trying to do this myself, without success (would gladly submit a PR if I could). I did create a custom profile, I'm messing with the variables on [rackFrame.scad](https://github.com/jazwa/rackstack/blob/main/config/rackFrame.scad) but I can't seem to get to the [supposed dimensions of a 10" rack](https://upload.wikimedia.org/wikipedia/commons/8/84/19_inch_vs_10_inch_rack_dimensions.svg), on width at least. I don't have experience with OpenSCAD and deciphering how everything is formed is proving a challenge (wish there was something like a debugger for this 😅). Would love any pointers here, will try the dimensions shared by @TeaRex-coder

Also, how do you guys verify dimensions? So far my process is:
1. Modify OpenSCAD files
2. Run `rbuild.py` to generate STLs
3. Import into Fusion 360, convert mesh to solid body
4. If necessary, manually align the parts together
5. Use the Inspect tool to measure

Which is very cumbersome. OpenSCAD nightly supposedly has a measurement feature, but I haven't been able to get it to work.

Thanks!

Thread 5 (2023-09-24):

[Feature Request] Would you ever consider making a version where the larger parts are laser cut?

rainyskye, 2023-09-24:
Only saying this as it could cut down on a lot of print times, and you could still produce a clean and interesting design using specific woods/acrylics (depending on flammability/safety treating)

drewgates, 2023-09-30:
An interesting idea. This would also make it producible out of steel or aluminum via SendCutSend or similar.

rainyskye, 2023-10-01:
True, I didn't even think of that to be honest, that would be more suitable to lab hardware :)

jazwa, 2023-10-04:
A lot of parts use specific geometries tailored for 3d printing; I don't know if they would be suitable for other fabrication methods. I think there's potential for the side+top panels to be laser cut? I don't have access to a laser cutter, so I can't really say. Tbh adding support for other fabrication methods (for this project) isn't really on my radar, but forks/prs are always welcome.

There are also some metal 3d printing services offered online though, if you're willing to shell out big bucks.

Closed 2024-08-26.

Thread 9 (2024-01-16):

[Question] How to print optional parts? i.e. Patch Panel, Tray, etc.

maygoo23, 2024-01-16:
Any guidance on what command to execute to generate these STLs?  Can't seem to figure it out.  Thank you

maygoo23, 2024-01-16:
Understand that OpenScad is the easiest method from another issue, sorry.

Closed 2024-01-16.

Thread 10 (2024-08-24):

rack-mount stls

Siopaos, 2024-08-24:
Dear Jazwa,
Thank you for your great work! Could you include the .stls for the beelink trays you made online? I fear I am too ignorant to create the .stl for a mini pc tray myself, and these would probably fit for me anyways.
Kind regards

jazwa, 2024-08-26:
I've added the config for this here: https://github.com/jazwa/rackstack/blob/main/rack-mount/catalog/beelink-mini-s-tray.scad

So all you should need to do is open the file using OpenSCAD, and then click on generate and save stl.

Closed 2024-08-26.

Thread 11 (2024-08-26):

How does the enclosed-box attach to the rack?

seantbaker, 2024-08-26:
Sorry if this is obvious, but I'm struggling a bit to visualize how the enclosed-box rails attach to the rack.

From the gifts of the enclosed-box and the assembly guide, I'd guess that the enclosed-box rails should attach with screws to each MainRail; there are rows of screw holes along the "sides" of the MainRails that I think would allow for that.

But when I render my enclosed-box parts, the supports on the rails are only ~50mm apart or so, which doesn't seem nearly far enough apart to attach to the MainRails. My rack dimensions are configured to be:

```
["custom", [
      ["maxUnitWidth", 236],
      ["maxUnitDepth", 102],
      ["numRailScrews", 16]
    ]],
```

I'm guessing that because my maxUnitDepth is 102mm, the screw holes in the enclosed-box rails (only ~50mm apart) won't line up with the mounting holes in the MainRails.

Am I missing something here? Or maybe I've got something misconfigured, and the enclosed-box rails should have their screw holes further apart?

jazwa, 2024-08-26:
I think what you have is correct. Yes, the side rails are to be mounted with the "side" holes of the main rail.

The `maxUnitDepth` here measures the distance between the "front" faces of the front and back main rails.

The distance between the front of the main rail, and the middle of the main rail's "side" hole is around 22mm (the distance here is only along the dimension representing "depth"). So `22mm + 22mm + 50 mm ~= 102 mm`.

I'm a bit fuzzy on this though. If you end up printing it and it doesn't work out please let me know.

mattnukem, 2024-09-27:
Did you set 'profileName = "micro";' to 'profileName = "custom"; in the rackFrame.scad file? If you don't change this, the entry.scad file will not grab the correct dimensions for your rack.

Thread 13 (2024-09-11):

PLA or ASA

casaerreti, 2024-09-11:
Hi there,

willing to print but concerned about temperatures.

Some of my device get quite hot and I don't think PLA will hold it.

Anyone printing this in ASA?

Any major hints to consider?

mattnukem, 2024-09-28:
I've got a set of four Minisforum MS-01's in a customized build printed entirely in PLA. The metal cases get a little warm, but not heat bed warm, so I'm worried about that. The one concern I have is the CPU fan exhaust, but so far it doesn't seem to be an issue. Granted these machines aren't under load that often.

We'll see how it holds up, but right now I have no concerns with PLA for these machines.

TechToasterTwo, 2024-11-15:
I've been using PLA and PETG with excellent results. Also, given the addition of the 120mm fan trays for additional cooling power, you may not need to worry about thermal thresholds as much anymore.

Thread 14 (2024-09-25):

Can't find rack-stack seen on the readme picture

GuideAuBug73, 2024-09-25:
Hello,

I wanted to know if it's possible to print the rack stack that can be seen in the repo picture . It would be really useful for my project.

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

Thank you in advance for your help.
And thank you for the work done on this project !

chaimt, 2024-09-28:
me too

jazwa, 2024-10-19:
I just added a mounting system for these brackets: [here](https://github.com/jazwa/rackstack/tree/main/rack-mount/angle-bracket). Just open up the `entry.scad` file in that directory with OpenSCAD and configure as you wish.

Closed 2024-10-19.

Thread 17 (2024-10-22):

Is 1.2.0 compatible with 1.1.1

kpoxo6op, 2024-10-22:
hello,

I orderd to print some of the `1.1.1` details in a local library. `1.2.0` was released while I was waiting.

My 1.1.1. printed details

```text
sideWallLeft_P  - 1x
sideWallRight_P - 1x
xyPlate_P       - 2x
xBar_P.stl      - 4x
yBar_P.stl      - 4x
```

Is 1.2.0 compatible with 1.1.1? Thanks.

jazwa, 2024-10-23:
Yes they should be. The only difference is that the yBars in `1.2.0` have the side modules attached to it already (like the hinge and magnet holders). The newer version just simplifies assembly and reduces the number of parts. How the parts fit together has not changed.

kpoxo6op, 2024-11-09:
>  side modules attached to it already

Just assembled my `v1.1.1`! Here is how `1.2.0` would be simpler.

`1.1.1` VS `1.2.0`
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

`1.1.1`: need to glue magnet and hinge holders
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

`1.2.0`: magnet and hinge holders are built in
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

Closed 2024-11-09.

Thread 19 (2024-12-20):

[Question] what are these called?

kpoxo6op, 2024-12-20:
hello

I printed default m3 case and tray:
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

can someone please tell me how do I call these "bolts" so I can order some for my case?
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

kpoxo6op, 2024-12-25:
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

Ok these were M4 screws and nuts sets

Closed 2024-12-25.

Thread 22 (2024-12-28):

Attempting to generate a rpi case for the nano profile

phptanker, 2024-12-28:
Hi! Great project I really love it! Successfully built one rack with the mini-profile so far:
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

I want to build a rackstack with the nano-profile for 1-2 raspberry pi's and a network patchbay, but I'm having trouble generating the file, see here:
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

I tried changing the length variable to 100 but then I ended up with this instead:
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

Any help is appreciated!

Best
Philip

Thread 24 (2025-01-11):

Rack-mount building?

jubjubrsx, 2025-01-11:
Okay I'm going to ask a stupid question, I'm new at this all and been trying to figure it out reading the python script and such...

for the life of me I cant figure out how to build like the patch panel or enclosed boxes? in the rack-mount directory. I'm guessing its something simple...

thank you

cmrdove, 2025-01-12:
> edit: got it had to update the default settings in the rackframe with the new width settings, then openscad export the stl...

This is what i have been doing too

jazwa, 2025-02-08:
That's what I do too! :) The script doesn't support those parts (yet). PRs are welcome!

cmrdove, 2025-02-08:
I'll attempt this when I get home thank you 👍

jubjubrsx, 2025-02-09:
@jazwa Awesome thank you for all your work on this project its great, its actually helped me learn scad (I didnt know it was a thing).

Since you mention PR's....

Not so much a PR but would be something really awesome is in the picture you can see I made a custom shelf, (made the initial shelf in openscad and imported into tinkercad for the honeycomb) being able to have a option to attach the shelf at the back of the rack just for a bit more support. For me not a major issue since I'm putting an enclosed box right below it.

Also something that would be great would be the ability to use more server standard screws (I think they are M6's) but that might also involve some major reworking on the rails and the rail mounts and thickness such like that.

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

xipher1, 2025-08-28:
@jubjubrsx I created a full honeycomb tray, you can see it here https://github.com/jazwa/rackstack/pull/43 hopefully it gets merged to the catalog.

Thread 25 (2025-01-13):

Patch panel rack model - Normalized tree growing past 200000 elements

cmrdove, 2025-01-13:
I have a rackframe that is 210x210 with 24 rail screws.
```
    ["custom", [
      ["maxUnitWidth", 210],
      ["maxUnitDepth", 210],
      ["numRailScrews", 24]
    ]]
```
Im attempting to generate a patch panel with a number of keystones (to be determined) to fill left to right, using both openscad (and openscad-nightly on debian bookworm).

Replicated on windows and linux.

When i attempt to generate a patch panel with anything above 8 keystones i get the following errors
```
WARNING: Normalized tree is growing past 200000 elements. Aborting normalization.
WARNING: CSG normalization resulted in an empty tree
```
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

When generating a patch panel with 8 or less it appears to generate ok.
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

jazwa, 2025-02-08:
Ran into this issue while working on https://github.com/jazwa/rackstack/issues/27. I just added a `render()` here: https://github.com/jazwa/rackstack/blob/0bd69808b42e3c780b175a7fb730b128318de076/rack-mount/patch-panel/patchPanel.scad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

Seems to help! Actually rendering the the stl with openscad (as opposed to just viewing the preview) always works for me too.

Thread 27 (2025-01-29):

Patch panel enhancements?

funk0id, 2025-01-29:
Has anybody had much joy with the patch panel?

For my rack width I'm able to generate 12 keystone spaces with the files, but I can't seem to centre them in any way? Can this be accomplished at all?

Ironically I won't be using it for keystone fittings just running cables through from two 8 port switches, but still want it looking relatively tidy!

jazwa, 2025-02-08:
Added an option to center the keystones: https://github.com/jazwa/rackstack/commit/0bd69808b42e3c780b175a7fb730b128318de076

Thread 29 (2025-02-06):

Enclosed box sideSupportRailBase expansion

funk0id, 2025-02-06:
I have some non-square kit, that's tapered at the base, so I've been trying to figure out how to expand what I believe is the "sideSupportRailBase" to allow the inner enclosed box to effectively "hug" the item more, so in my case the bottom support rail base is wider than the top, or both are wider than the default model?

I've attached the screenshot from OpenSCAD file to help explain what I'm trying to expand where the red arrow is?

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

Is this a limitation of the model, or can it be done, I'm still learning!

jazwa, 2025-02-08:
I believe this is configured with sideRailBaseWidth: https://github.com/jazwa/rackstack/blob/1487717966237741d3c32730edb2c927741b966d/rack-mount/enclosed-box/helper.scad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

Might make sense to move that to the `entry.scad` file.

funk0id, 2025-02-11:
That's worked perfectly thanks so much! Can't believe I couldn't find it!

Closed 2025-02-11.

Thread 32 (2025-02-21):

Add numbering / naming option to patch panel

timoknapp, 2025-02-21:
It would be great to have the option to set a numbering and or naming for each of the panel ports. Would be cool if it was configurable, so either:
- Numbering (auto): `1,2,3,4,5,6,...`
- List of text: `["LAN", "EXT", "RASPI"]`

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

jazwa, 2025-03-15:
Yea, this would be very useful.

We're probably about to make some changes to the default patch panel: https://github.com/jazwa/rackstack/pull/35#issuecomment-2692344825 and this should actually free up some space for lettering.

If I were to add it it would probably be as an argument here: https://github.com/jazwa/rackstack/blob/179c0e530f774c3e80d4e23a7419dd98865fb64c/rack-mount/patch-panel/patchPanel.scad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

and make the changes within that function

Only thing I'm unsure of is how legible the printed part would look like

poxin13, 2025-06-30:
Getting started on my own print and was looking for this feature.

In regards to legibility, a common printing technique would be doing a color swap in order to make the text stand out. You could ether have the letters extend beyond the top layer height of the bracket (emboss) and swap colors for the lettering, or the opposite (deboss) but this would have a couple layers be a different color, which sometimes isn't an issue. My printer for example can do multi-color on the same layer and would work fine too.

Either way, labels would be great!

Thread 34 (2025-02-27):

M3 Washers do not fit in slots

jbnels, 2025-02-27:
M3 washers do not fit in their slots.  What values need to be adjusted?  Most slots are too small in both height and width.

jazwa, 2025-03-15:
Do you mean the hex nuts? Are you having trouble fitting other things? like plastic on plastic parts.

s2kwinston, 2025-04-03:
> Do you mean the hex nuts? Are you having trouble fitting other things? like plastic on plastic parts.

I have the same problem. Dovetails fit fine, but the washers don't fit in the slots. Z seems fine, the slots seem too short. Screws go into their holes just fine too.

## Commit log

2022-04-10 work work work work work work
    [base.scad, newcase.scad, newcase.stl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]
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2022-06-02 fix box rack<
    [rackCaseForBox.scad, rackCaseForBox.stl]
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2022-09-25 i really need to clean this up
    [dual-tray-plate-part.scad, dual-tray-plate-part.stl, dual-tray.scad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]
2023-01-01 parametrize screw/hex nut types
    [config.scad, mainRail.scad, screws.scad]
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2023-01-08 rename connectingBar to yBar, and add mockup of new xBar. Also mess around with the full assembly
    [assemble.scad, config.scad, connectingBar.stl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]
2023-01-09 reorganize old files, and update readme with banner image
    [common.scad, math.scad, open-frame.scad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]
2023-01-11 add stl file in new location, also rename assembly.scad to fullAssembly.scad
    [fullAssembly.scad]
2023-01-12 add custom connector files
    [sideWallConnector.scad, xyBarConnector.scad, yBar.scad]
2023-01-12 add some prep files
    [derivedConfig.scad, halfspace.scad, math.scad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]
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2023-01-13 add to xBar, also refactor
    [config.scad, derivedConfig.scad, halfspace.scad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]
2023-01-13 wip on base connector
    [common.scad, screws.scad, xBar.scad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]
2023-01-14 fix yBarBasePlateConnector
    [yBarBasePlateConnector.scad]
2023-01-14 refactor yBar with new application pattern
    [config.scad, yBar.scad, yBar.stl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]
2023-01-14 rename inner modules for clarity in yBar
    [yBar.scad]
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2023-01-16 fix xBarDepth
    [config.scad, xBar.scad]
2023-01-17 refactor yBar to include better variables
    [mainRail.scad, sideWallConnector.scad, yBar.scad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]
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2023-01-18 fix xBar
    [mainRail.scad, xBar.scad]
2023-01-22 revert yBar changes, also WIP on side connectors and side wall
    [derivedConfig.scad, halfspace.scad, mainRail.scad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]
2023-01-27 wip on magnet side wall connector
    [math.scad, sideWallConnector.scad]
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2023-01-29 sideWall wip - need to clean up
    [sharedVariables.scad, sideWall.scad, sideWallConnector.scad]
2023-02-04 WIP on sideWall and sideWallConnector
    [mainRail.scad, sharedVariables.scad, sideWall.scad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]
2023-02-05 split sideWallConnector into parts
    [hingeModule.scad, magnetModule.scad, sideWall.scad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]
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2023-02-12 add new print-friendly folder, and update rbuild accordingly. also refactor+fix xBar
    [fullAssembly.scad, hingeModule.scad, hingeModule_P1.scad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]
2023-03-05 add/fixup hinge clearance
    [common.scad, hingeModule.scad, magnetModule.scad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]
2023-03-10 improvements to side wall hinge
    [hingeModule.scad, magnetModule.scad, sideWallBase.scad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]
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2023-03-18 fix stack connector slack application
    [stackConnector.scad]
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2023-03-19 update some tolerances
    [stackConnector.scad, stackConnectorPlugBase_P.stl, xyBarConnector.scad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]
2023-03-19 update stl and tolerances
    [xBar.scad, xBar_P.stl, yBar_P.stl]
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2023-03-22 small fix
    [xyBarConnector.scad, yBar_P.scad]
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2023-03-24 increase sideWallConn height by a full 1mmgit add --all!
    [hingeModule_P1.stl, magnetModule_P1.stl, magnetModule_P2.stl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]
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2023-03-26 update tolerances for x-y connectors
    [hingeModule_P1.stl, magnetModule_P1.stl, magnetModule_P2.stl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]
2023-03-31 add wip side mount l-bracket. also update mainRail with flush screws
    [dualMount.scad, hingeModule_P1.stl, magnetModule_P1.stl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]
2023-04-01 add rack-mount build directory, add stack mount stls, and some general fixes
    [dualLBracketSupportRail_P1.scad, dualLBracketSupportRail_P1.stl, dualLBracketSupportRail_P2.scad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]
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2023-04-08 introduce slack config fale. also small edits to side wall stuff
    [hingeModule_P1.stl, magnetModule_P1.stl, magnetModule_P2.stl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]
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2023-05-12 add missing instructions
    [assemblyGuide.scad, common.scad, hingeModule.scad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]
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2023-05-21 Cleaning up - Update python script and readme
    [dualLBracketSupportRail_P1.stl, dualLBracketSupportRail_P2.stl, features.scad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]
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2023-06-16 update stls and build script with custom target
    [dualLBracketSupportRail_P1.stl, dualLBracketSupportRail_P2.stl, eval_P.stl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]
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2023-06-18 fix render
    [eval_P.stl, mainRail.scad, mainRail_P.stl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]
2023-06-24 refactor - introduce config folder, and other misc changes
    [apply.scad, assemblyGuide.scad, basePlateYBarConnectors.scad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]
2023-06-24 fix facet num issue
    [common.scad, eval_P.stl, hingeModule.scad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]
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2023-08-08 rename and update print files for rack mount
    [dualLBracketSupportRail_P1.scad, dualLBracketSupportRail_P2.scad, eval_P.stl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]
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2023-08-10 fix screws
    [screws.scad]
2023-08-11 introduce script to generate assembly animation. still needs cleanup
    [addMagnetsToMagnetModules.scad, addMagnetsToSideWall.scad, attachSideConnectorModulesToYBars.scad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]
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2023-08-13 fix ventilation for sidewalls
    [rackFeet_P.scad, rackFrame.scad, rackJoiner_P.scad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]
2023-08-13 fix rbuild script
    [eval_P.stl, finalBuilds.scad, frontBoxHolder_P.stl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]
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2023-08-29 improve support side rail. also begin refactoring rack-mount to make more friendly
    [boxHelper.scad, sideRail.scad, sideSupportRail_P1.scad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]
2023-08-31 Improve rack-mount. Individual rack-mount systems are now organized in their own directories, with a standard entry.scad file.
    [boxHelper.scad, common.scad, entry.scad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]
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2023-09-01 add animation gifs for new rack-mount systems, also update rbuild and the main readme to reflect these changes
    [animate.scad]
2023-09-04 fix screw slack value
    [screws.scad]
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2024-02-25 fix extra slack being applied to hex nut pockets, should help with slipping
    [print.scad, screws.scad]
2024-02-25 side wall improvements: add option to not include ventilation holes for side walls, and add horizontal bracing
    [common.scad, eval_P.stl, hingeModule.stl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]
2024-04-26 Small fix to one-off rpi case
    [case.scad]
2024-08-26 Add new catalog directory to store various rack-mount part configs. Also add some old beelink and mele mini pc tray configs.
    [beelink-mini-s-tray.scad, case.scad, entry.scad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]
2024-08-26 Small comment fix
    [beelink-mini-s-tray.scad]
2024-10-19 Add option for fixed side modules. This simplifies assembly and removes some awkward printing topology
    [addMagnetsToMagnetModules.scad, attachSideConnectorModulesToYBars.scad, attachXBarWithYBar.scad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]
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2024-11-21 120mm Fan Tray + 3 mini pc trays (#18)
    Add 120mm Fan Tray + 3 mini pc trays
    NOT COMPATIBLE WITH NANO PROFILE
    The Fan tray and Mini PC trays in this pull request are only compatible with the Micro and Mini rackstack profiles.
    [120mm-fan-tray_mod.scad, Minisforum_NAB9-tray_mod.scad, Minisforum_UM890PRO-tray_mod.scad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]
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2025-03-18 Add new catalog items (#39)
    120mm Rear Case Fan - Designed to be mounted on the rear face of the rack, with the case holding the fan on the exterior of the rack rather than the interior.
    Beelink EQi12 Box - I originally created a Tray for the EQi12, but with it's lack of mounting points the device would shift. This box is the same as the enclosed box, however with the specific measur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
    Unifi 8 port PoE Switch - I originally intended to use the Enclosed Box for this, however due to the bevels on every corner of this device, the box was unable to secure the switch. Instead, I created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
    [120mm-Rear-Case-Fan.scad, Unifi-8-PoE-Switch_Tray+Adapter.scad, beelink-EQi12-box_mod.scad]
2025-03-21 Rewrite keystone.scad (#35)
    * helper/keystone: rewrite completely
    * rack-mount/patch-panel: edit to adapt to the new keystone
    * helper/keystone: fill the lug-side opening
    * rack-mount/patch-panel: allow combining two types of keystones and
    plates freely
    * rack-mount/patch-panel/entry: apply suggestions
    * rack-mount/patch-panel: fix animate.scad & regen gif
    ---------
    [animate.scad, common.scad, entry.scad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]
2025-03-22 A brush strip plate for hiding and managing a Rackstack's cable shame. (#38)
    * A brush strip plate for hiding and managing a Rackstack's cable shame.
    * - Renamed plateZ to plateThickness to be more consistent with the rest of the project
    - Cleaned up unused code
    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
    [brush-strip-plate.scad]
2025-05-18 LG Slim Portable DVD Reader/Writer Tray (#41)
    * Add files via upload
    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
    [LG_Slim_DVD_Tray.scad]
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
